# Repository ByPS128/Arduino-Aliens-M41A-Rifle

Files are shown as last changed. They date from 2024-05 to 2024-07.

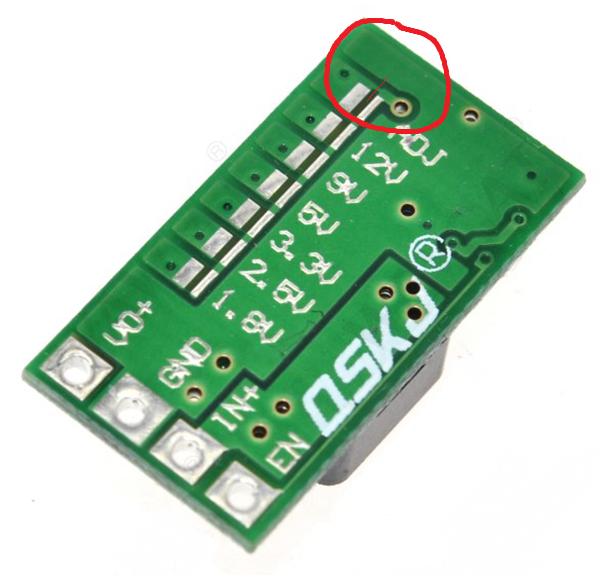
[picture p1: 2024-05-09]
doc/Micro Step-Down Converter-Adjustable/Micro Step-Down Converter-Adjustable.png

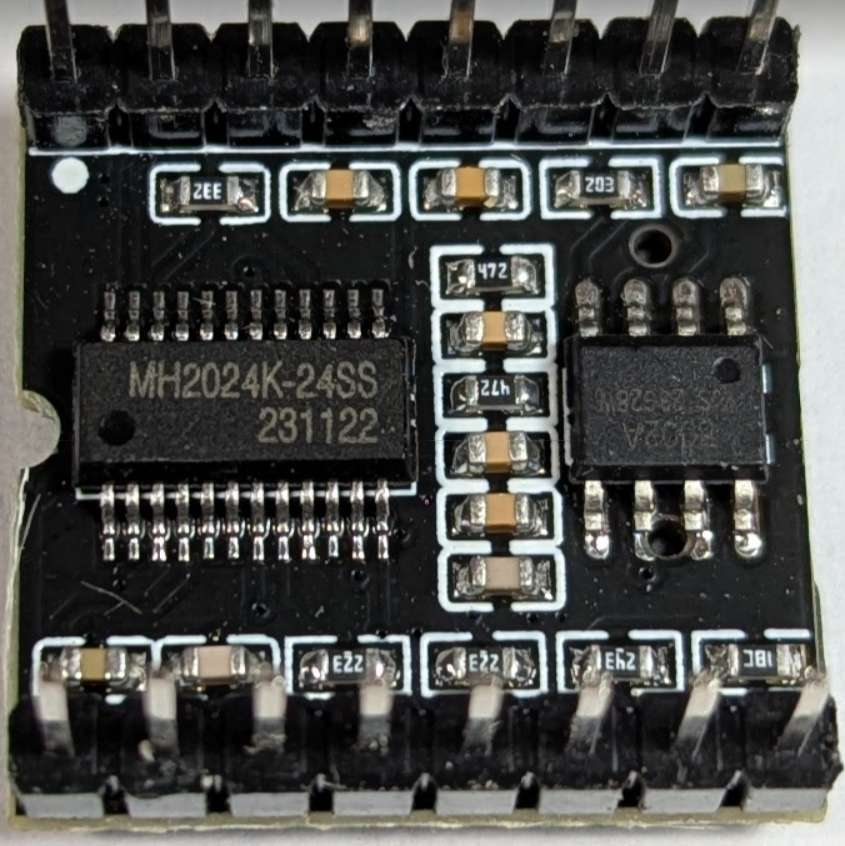
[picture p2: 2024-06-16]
doc/BAD-chip-photo/MH2024K-24SS.png

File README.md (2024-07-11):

# Welcome,

the project is a simple simulator of rifle and grenade launcher firing mockups of the popular M41A weapon from the legendary Aliens movie.
The hardware is implemented using an Arduino Nano and a DF Player (also known as the DF Robot) along with a few other peripherals.

#### In the document I will describe both HW and SW, browse it to the places you are interested in.

## So what does intended HW version consist of:

There are many M41A mock-ups on the market, including 3D printed ones. The version I was sounding did not have a working grenade launcher and it also did not have a retractable slide. We used the magazine space to house the electronics and so this version of the 3D printed rifle has quite a lot of limitations.
However, the software is easy to adapt for a larger application with multiple input signals.

* Arduino Nano
* DF Player for reproducing sounds
* Rotary Encoder with button to control volume, can be without button and it will work without the whole rotary encoder
* LED to illuminate the flashes in the barrel of the rifle
* LED to illuminate the barrel of the rifle
* Button to trigger the rifle's firing pin
* Button to trigger loading / firing of the grenade launcher
* Button to trigger the sound of the rifle bolt retracting
* Button to play magazine change sound
* Double digit 7 segment display
* Required resistors, capacitor and shocky protection diode

## 3D print
I made a 3D models of magazine foot where I placed:
* battery
* switch for turning on/off
* rotary encoder to adjust volume

You can use my 3D models for 3D printing if compatible with yours models of M41A rifle.

I will be glad if you use them, see here at Printables.com:

https://www.printables.com/cs/model/940214-m41a-rifle-magazine-foot-for-arduino-implementatio



I am using OnShape to create models, here is direct link if you are interested in:
https://cad.onshape.com/documents/143c32e288eb70a4674d24e8/v/e97b14a1ca8f76a05194cd48/e/891a4cec0397cb99cd8f56b7



## Want see how it works?
Here is updated video of the project in action with description of all functions:

https://www.youtube.com/watch?v=IwG0UBBIASA



## Schematic

I developed the scheme in KiCad (free). It's my first schematic, so please excuse me if I didn't choose some brands correctly. Alternatively, please modify the scheme and make a pull request. The schematic source files are in the KiCad directory.

https://www.kicad.org/

Schema preview:
M41A-Schematic

## Schama descriptions about condensators used as filter of peaks and noise:
To prevent the display from flickering after switching on the circuit, or even a flicker in the speaker, I recommend using an electrolytic and ceramic capacitor in parallel. Each type has different characteristics and they complement each other:

* 100 µF electrolytic capacitor: This capacitor is able to smooth out low frequency peaks and provide a stable power supply. Electrolytic capacitors have high capacitance and are suitable for low frequency filtering.

* 100 nF ceramic capacitor: This capacitor is capable of smoothing out high frequency peaks and noise. Ceramic capacitors have lower capacitance but are faster and more efficient for filtering high frequencies.

### So you should use both types of capacitors in parallel:
* Electrolytic capacitor **C1** (100 µF) between VCC and GND.
* Ceramic capacitor **C2** (100 nF) between VCC and GND.

### The order of the capacitors in the direction from source to consumer matters:
1. Ceramic capacitor (100 nF): this capacitor should be as close as possible to the power pins of the components (i.e. to the consumers). Ceramic capacitors are able to quickly filter out high frequency noise, which is useful for removing fast changes and interference.
2. electrolytic capacitor (100 µF). Electrolytic capacitors have higher capacitance and are able to smooth out low frequency peaks and stabilize the power supply.

## Estimation of current consumption
### Components:
* Arduino Nano: approximately 50 mA
* DFPlayer Mini: approximately 150-250 mA (without speaker)
* Speaker: up to 600 mA (at maximum power)
* Display with 74HC595: approximately 50-100 mA
* Other components (LEDs, switches, etc.): approx. 20-50 mA

### Total estimated current consumption
Approximately 870-1050 mA (considering all components at maximum power)

Calculation of capacitor capacitance required
It is common practice for filter capacitors to use 100-200 µF for every 100 mA of current draw.

Electrolytic capacitor **C3**
Required capacitance: (1050 mA / 100 mA) * 100-200 µF = 1050-2100 µF
Ceramic capacitor **C4**
Capacitance required: 100 nF to 1 µF (for high frequency noise)

### Recommended capacitances for capacitor.

#### C3 (electrolytic capacitor)
Recommended capacitance: 1000 µF to 2200 µF
This value will provide sufficient power supply filtering for all components.

#### C4 (ceramic capacitor)
Recommended capacitance: 100 nF to 1 µF
This value will help with high frequency noise filtering.

Schema file resides here: /KiCad/M41A/M41A.kicad_sch

and here is PDF version: /KiCad/M41A-Schematic.pdf

If you would like to open the schema, import the libraries I created. I couldn't find schematic marks for some components, so I created them with their footprints.
The library is in the directory: /KiCad/Project_Library.kicad_sym

### DF Player

I decided to use DF Player for playing sounds for several reasons:

* Low purchase price
* The possibility of controlling the serial line with its own simple protocol
* Clear organization of sound files on the SD card
* A large number of existing compatible libraries to support the protocol

However hend I made the experience that not every clone works properly. I was unlucky and the very first one I bought was built on the `MH2024K-24SS` chip. This has huge latency from the instruction to play the audio to the actual start of playback takes a second.
And that's unusable. That's why I bought a few more from different stores and came across a module with a `TD5580A` chip and it responds instantly. And that's why I recommend you use it. 

I used the protocol handler from an existing library and modified it to suit me better.

### Speaker

I used a 3W speaker. The specification of the DF Player says that the built-in amplifier will drive the 3W speaker to the maximum.
If you wanted to use a more powerful speaker, you would have to insert another amplifier between the player and the speaker and use a separate power supply.

**You can find the documentation for the DF player in the DOC directory, including communication protocol specs.**

### 2 digit 7 segment display

For displaying the remaining bullets in the rifle's magazine, I used, how else, red segment displays. And to get rid of a bunch of wires and resistors, I used a driver that is beautifully compact, works perfectly.
It contains a 74HC595 circuit for each segment. The displays used shared anode, so the segment lights up when its pin is at logic zero.



https://www.aliexpress.us/item/3256805033000283.html

### Rotary Encoder with button

I used this one, with built-in RC filter. Thanks to the filter, the dream was not to treat false presses.



https://www.aliexpress.us/item/3256805548024336.html

### LED diods

I used high brightness 5mm, warm white, 30mA LEDs
https://www.gme.cz/v/1492064/OptoSupply-OSM5DK5201A-LED-5mm-tepla-bila

## What this module can do, how it was designed

* Pressing and holding the trigger of the rifle starts playing the sound of firing and with each round fired the LED flashes to simulate a flash. At the same time, each shot will be read from the counter.
* When all rounds have been fired, the display shows 00 and the sound of the hammer striking empty is heard.
* Each subsequent pull of the trigger with an empty magazine will play this sound.
* The slide release button will also cause the magazine to load to 95 and cause the slide release sound to play.
* The magazine change button will set the magazine count to 95 rounds and trigger the magazine change and slide release sound.
* the grenade launcher trigger button will load a grenade with one press and play a sound consisting of several: chamber opening, grenade insertion and chamber closing.
* another press of the grenade launcher trigger will fire the grenade and play the sound of the grenade being fired. At the same time, the time to wait for the grenade to explode is randomly calculated. The next press of the grenade launcher trigger repeats charge, shot, charge, shot, etc.
* Rotating the rotary encoder changes the volume. When the gun is at rest and you change the volume, the display shows the volume numbers. The volume can also be changed while the sounds are playing. If a firing sound is playing and you are changing the volume, the display shows the cartridge level in the magazine as a priority.
* Pressing/pushing on the rotary encoder has 2 functions. A short press shows the current volume value on the display. A long press (a second or more) causes the status to be entered 

## Other features:

I made some sounds in multiple variations. This is so that the simulation does not appear monotonous. So every time I start shooting, a different option comes up. They repeat over time, but for the shot I made it so that each new playback plays a different file.
Similarly, the pulling of the weapon's bolt is solved, the sound of squeezing the trigger with an empty magazine is also solved.

## Sounds on SD card

The program is somehow built and expects concrete files on the sd card. DF Player uses mtak that I select a directory and a file in it. This is defined by numbers. So the directories are numbered and always with two digits, i.e. "01". I don't use them anymore. It would be easy to use the rotary encoder to select a different directory and thus select a different set of sounds, and suddenly the sounds could be from a specific existing weapon, or totally crazy sci-fi sounds, etc. In directory 01 there are files that must also be numbered in 3 places, i.e. 001, 002, etc. In the constants of the application, it is then defined which number has which sound.
For example (excerpt from AppConstants.h)

```
// I have some sounds in multiple variants and I randomly choose which variant to play.
// For this there are FIRST and LAST containers, which define the file numbers of the sounds of a given type.

// Sound file interval for rifle fire
static const int SAMPLE_RIFLE_FIRE_FIRST = 1;
static const int SAMPLE_RIFLE_FIRE_LAST = 6;

// Sound file interval for cock sound
static const int SAMPLE_COCK_FIRST = 10;
static const int SAMPLE_COCK_LAST = 14;

// Sound file interval for empty magazine, you rpes rifle fire and this empty file will play
static const int SAMPLE_EMPTY_MAGAZINE_FIRST = 20;
static const int SAMPLE_EMPTY_MAGAZINE_LAST = 24;
```

## File list on SD card.

Files must start with a number, but can continue with any name that describes the sound.
This is what my SD card looks like:

```
001-Shoot-95.wav
002-Shoot-95.wav
003-Shoot-95.wav
004-Shoot-95.wav
005-Shoot-95.wav
006-Shoot-95.wav
010-Cock-01-Sniper.wav
011-Cock-02.wav
012-Cock-03.wav
013-Cock-04.wav
014-Cock-05.wav
020-Empty.wav
021-Empty.wav
022-Empty.wav
023-Empty.wav
024-Empty.wav
030-MagazineEject-01.wav
031-MagazineEject-02.wav
040-MagazineLoad-01.wav
041-MagazineLoad-02.wav
042-MagazineLoad-03.wav
050-MagazineReload-01.wav
051-MagazineReload-02.wav
053-MagazineReloadCock-01.wav
054-MagazineReloadCock-02.wav
060-GranadeFire-01.wav
061-GranadeFire-02.wav
062-GranadeFire-03.wav
065-GranadeLoad-01.wav
066-GranadeExplosion-01.wav
067-GranadeExplosion-02.wav
070-Volume-01-Down.wav
071-Volume-02-Down.wav
072-Volume-03-Down.wav
073-Volume-04-Down.wav
074-Volume-05-Down.wav
080-Volume-01-Up.wav
081-Volume-02-Up.wav
082-Volume-03-Up.wav
083-Volume-04-Up.wav
084-Volume-05-Up.wav
090-CardInserted.wav
091-CardRemoved.wav
092-LowBattery.wav
093-VolumeSaved.wav
094-WeaponReady.wav
095-Click-01.wav
```

But in reality, the application, as its source codes define, uses the following files:
(Starting to play unused sounds is commented out in the application.)

```
001-Shoot-95.wav
002-Shoot-95.wav
003-Shoot-95.wav
004-Shoot-95.wav
005-Shoot-95.wav
006-Shoot-95.wav
010-Cock-01-Sniper.wav
011-Cock-02.wav
012-Cock-03.wav
013-Cock-04.wav
014-Cock-05.wav
020-Empty.wav
021-Empty.wav
022-Empty.wav
023-Empty.wav
024-Empty.wav
053-MagazineReloadCock-01.wav
054-MagazineReloadCock-02.wav
060-GranadeFire-01.wav
065-GranadeLoad-01.wav
066-GranadeExplosion-01.wav
093-VolumeSaved.wav
```

It is also essential to use the DriveSort app: [Anerty's Lair - DriveSort](https://www.anerty.net/software/file/DriveSort/) which sorts the files on the SD card so that they are physically organized in sequence.
This has a major impact on the delay/latency before the sound starts playing.

## How I made the sounds.

I searched in sound banks which provides free sounds for free download and use.
For example, I searched for gun cocking sounds under the keyword "cock" and one of the many useful ones I found is, for example, this one:
https://artlist.io/sfx/track/battle-rifles---fn-fal-cocking-gun/80693

It will probably take you some time to find the right sounds that you will like and fit for your application.

The firing of the M41A rifle is specific sound and is difficult to imitate. So I bought the game "Aliens Colonial Marines" and used the sounds from it.

To edit the sounds, I used the AudaCity software, which is free and can do everything necessary in it.
[https://www.audacityteam.org/](https://www.audacityteam.org/)

## Audio file format

DF Player can play many formats including MP3 in CD quality and stereo.
(It even has a simple equalizer, but I haven't used it, but you can, I have implemented functions to adjust the equalizer, just use them.)

The connection I used is monophonic, so using files containing stereo tracks is unnecessary workload for DF Player, and also such files are larger, which means that more power and time are needed to upload and process the file.
And this app (M41A) works well only when it responds instantly.
So, for these reasons, even after several attempts and tests, I decidedto use uncompresed WAV format, 8bit, mono with 22050 sample rate.
It sounds as good from that 3W speaker as the 16bit mono 44100. If you used a better speaker, then it is possible that you would use a better quality sound.

If you would use better quality sounds, there is no need to change anything in the application. The detection of the audio file format is fully under the control of DF Player.

When I wrote about organizing files on the SD card above, I mentioned the 01 directory that I use.
But you can easily have more such directories and the same numbered files in them. These can contain the same but higher quality sounds. By simply changing the value of one constant, you tell the application to use a different directory. And so you can easily test which sounds are better in your application.
The constant is named `DEFAULT_DIRECTORY_NUMBER` and resides in DFPlay.h file

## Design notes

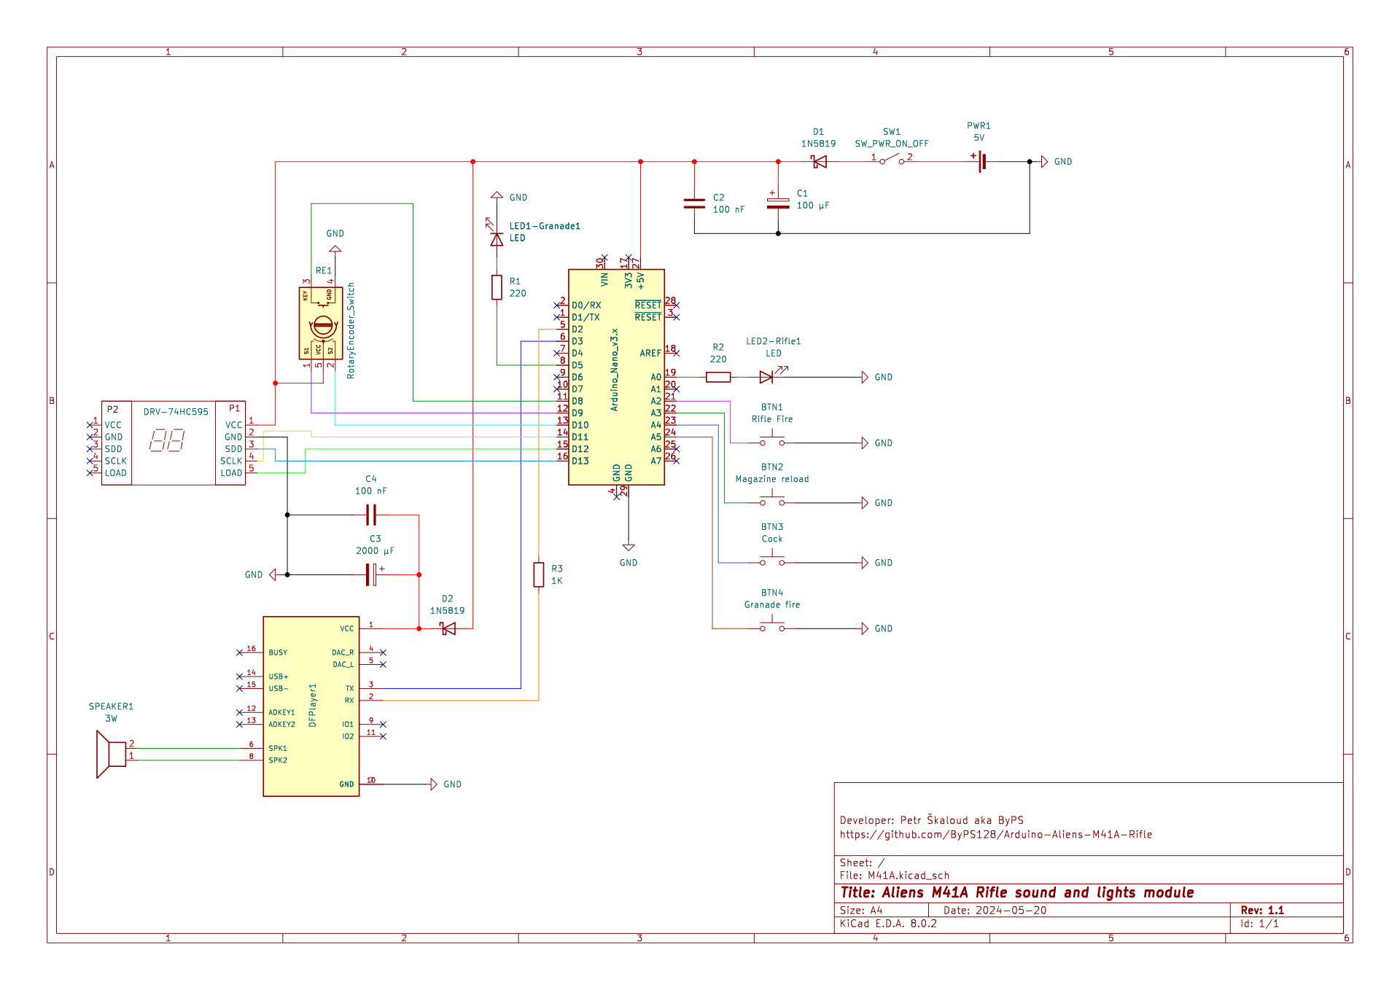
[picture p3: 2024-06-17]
KiCad/M41A-Schematic.png

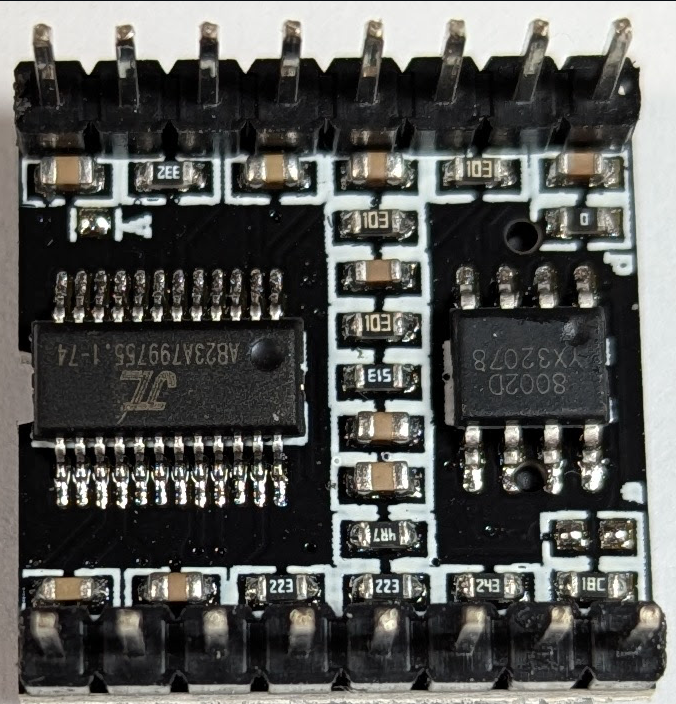
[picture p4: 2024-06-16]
doc/GOOD-chip-photo/A823A799755.png

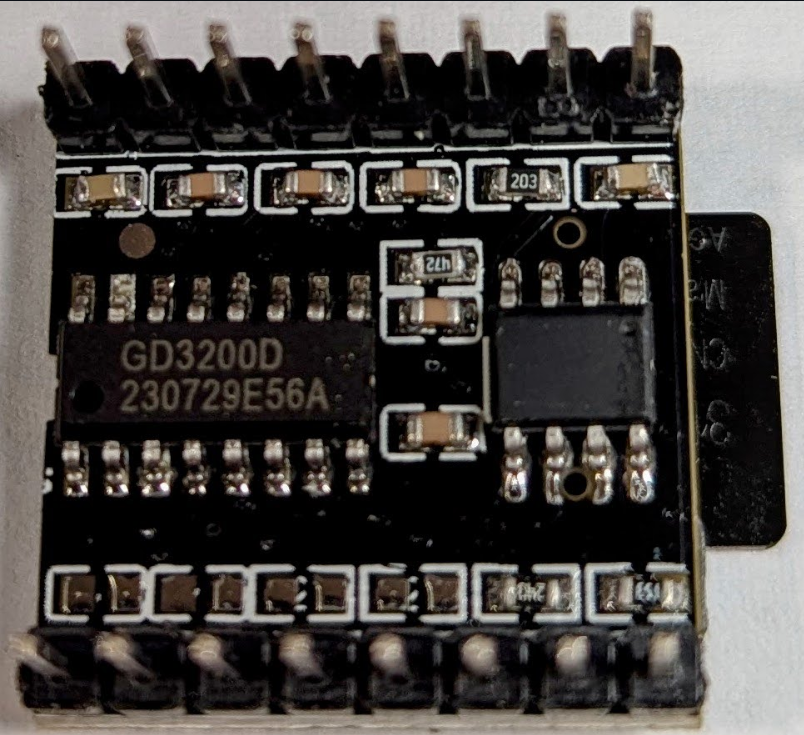
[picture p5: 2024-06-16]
doc/GOOD-chip-photo/GD3200D.png

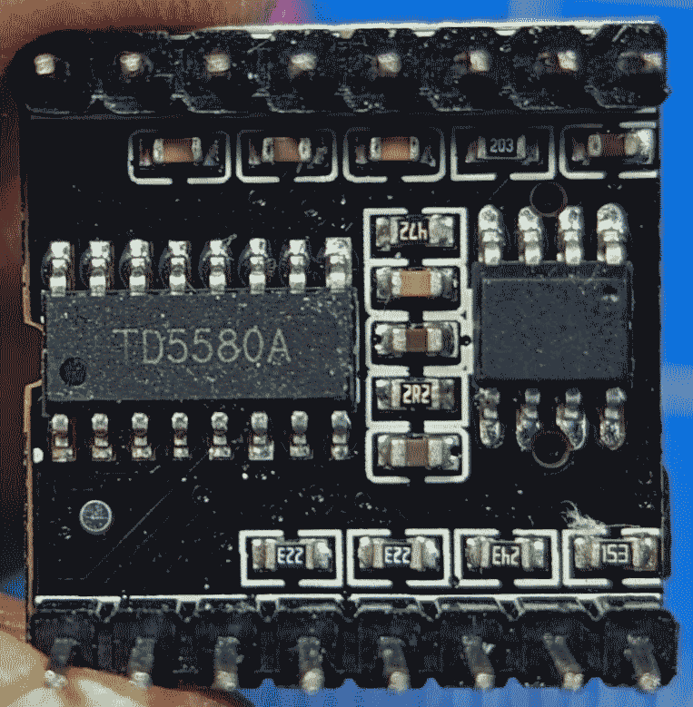
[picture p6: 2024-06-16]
doc/GOOD-chip-photo/TD5580A.png

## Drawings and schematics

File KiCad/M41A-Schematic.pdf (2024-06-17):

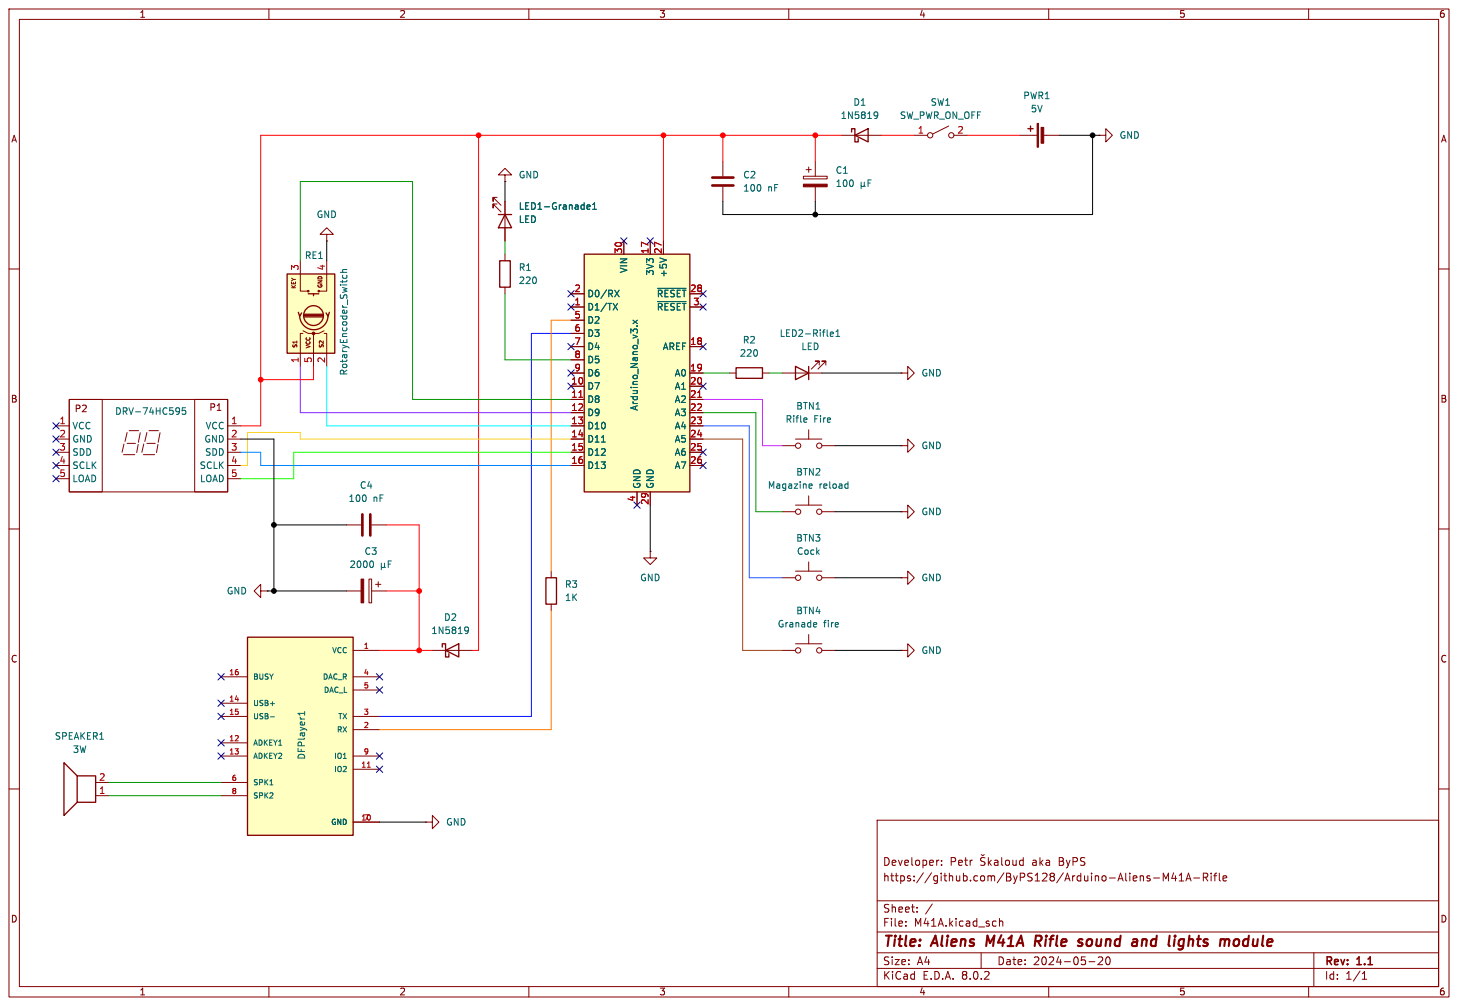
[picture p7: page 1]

File: M41A.kicad_sch Sheet: / https://github.com/ByPS128/Arduino-Aliens-M41A-Rifle

Id: 1/1 Title: Aliens M41A Rifle sound and lights module

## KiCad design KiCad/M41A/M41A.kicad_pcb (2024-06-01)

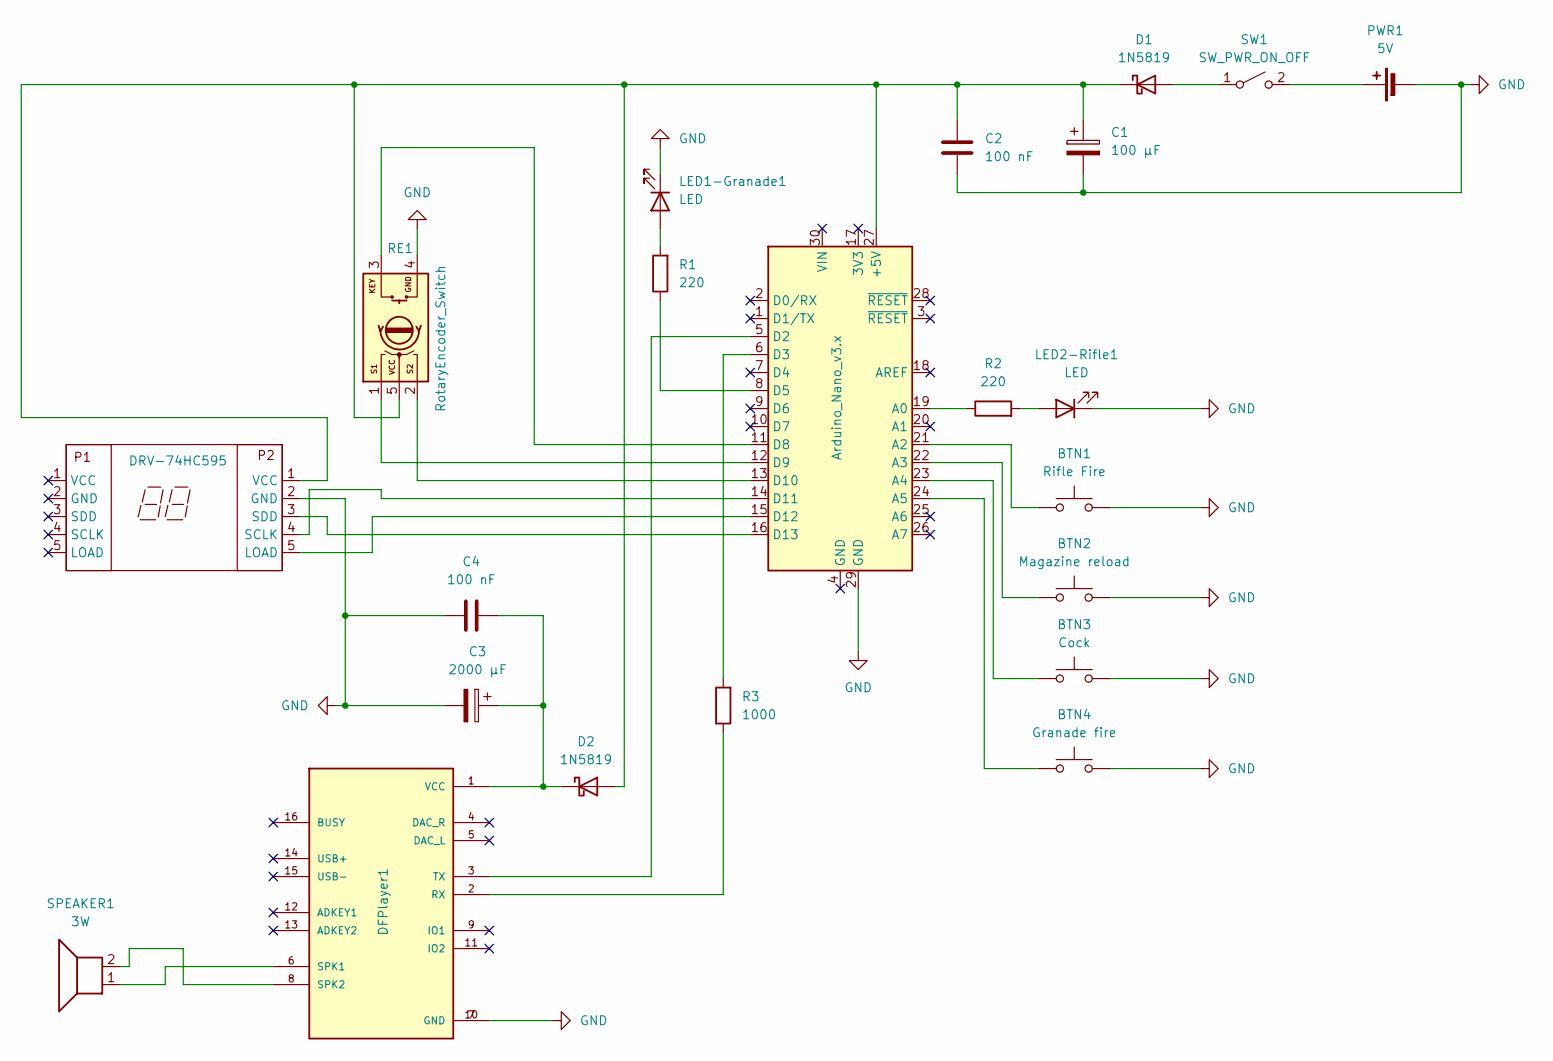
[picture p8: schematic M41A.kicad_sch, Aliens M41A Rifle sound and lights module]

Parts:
A1: Arduino_Nano_v3.x; Arduino_Nano
BTN1: Rifle Fire; Button Leads 2x 2.54
BTN2: Magazine reload; Button Leads 2x 2.54
BTN3: Cock; Button Leads 2x 2.54
BTN4: Granade fire; Button Leads 2x 2.54
C1: 100 µF; CP_Radial_D5.0mm_P2.50mm
C2, C4: 100 nF; C_Rect_L4.0mm_W2.5mm_P2.50mm
C3: 2000 µF; CP_Radial_D5.0mm_P2.50mm
D1, D2: 1N5819; D_DO-41_SOD81_P10.16mm_Horizontal
DFPlayer1: DFPlayer; MODULE_DFR0299
DRV-74HC595: Segment Display Leads 5x 2.54
LED1-Granade1, LED2-Rifle1: LED; LED Leads 2x 2.54
PWR1: 5V; Battery 4x 2.54
R1, R2: 220; R_Axial_DIN0204_L3.6mm_D1.6mm_P7.62mm_Horizontal
R3: 1000; R_Axial_DIN0204_L3.6mm_D1.6mm_P7.62mm_Horizontal
RE1: RotaryEncoder_Switch; RotaryEncoder Leads 5x 2.54
SPEAKER1: 3W; Speaker Leads 2x 2.54
SW1: SW_PWR_ON_OFF; SW_DIP_SPSTx01_Piano_10.8x4.1mm_W7.62mm_P2.54mm

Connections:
GND: A1.29 (GND), BTN1.2, BTN2.2, BTN3.2, BTN4.2, C1.2, C2.2, C3.2, C4.1, DFPlayer1.7 (GND), DFPlayer1.10 (GND), DRV-74HC595.2 (GND), LED1-Granade1.1 (K), LED2-Rifle1.1 (K), PWR1.2 (-), RE1.4 (GND)
unnamed: A1.27 (+5V), C1.1, C2.1, D1.1 (K), D2.2 (A), DRV-74HC595.1 (VCC), RE1.5 (VCC)
unnamed: A1.19 (A0), R2.1
unnamed: A1.21 (A2), BTN1.1
unnamed: A1.22 (A3), BTN2.1
unnamed: A1.23 (A4), BTN3.1
unnamed: A1.24 (A5), BTN4.1
unnamed: A1.5 (D2), DFPlayer1.3 (TX)
unnamed: A1.6 (D3), R3.2
unnamed: A1.8 (D5), R1.1
unnamed: A1.11 (D8), RE1.3 (KEY)
unnamed: A1.12 (D9), RE1.1 (S1)
unnamed: A1.13 (D10), RE1.2 (S2)
unnamed: A1.14 (D11), DRV-74HC595.4 (SCLK)
unnamed: A1.15 (D12), DRV-74HC595.5 (LOAD)
unnamed: A1.16 (D13), DRV-74HC595.3 (SDD)
unnamed: D1.2 (A), SW1.1 (A)
unnamed: C3.1, C4.2, D2.1 (K), DFPlayer1.1 (VCC)
unnamed: DFPlayer1.2 (RX), R3.1
unnamed: DFPlayer1.6 (SPK1), SPEAKER1.1
unnamed: DFPlayer1.8 (SPK2), SPEAKER1.2
unnamed: LED1-Granade1.2 (A), R1.2
unnamed: LED2-Rifle1.2 (A), R2.2
unnamed: PWR1.1 (+), SW1.2 (B)

Board: 2 copper layers, 22 parts (0 on the bottom side), 24 nets, no tracks yet.

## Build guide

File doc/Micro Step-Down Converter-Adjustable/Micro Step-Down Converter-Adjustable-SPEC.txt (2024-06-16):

Product link:
https://www.tinytronics.nl/en/power/voltage-converters/buck-(step-down)-converters/mini-dc-dc-adjustable-step-down-buck-converter-2a
https://www.laskakit.cz/mikro-step-down-menic--nastavitelny/

English:
Detailed Product Description
Micro Step-Down Converter, Adjustable
If you want to work with high current, ensure proper heat dissipation!

According to available information, there are modules on the market that are not equipped with the original chip and can cause damage to the electronics connected to such a module. The modules we supply are equipped with the original chip marked |AGC(N).

Specifications:
Control Circuit: MP2315
Input Voltage: DC 4.5-24V
Output Voltage: Adjustable and fixed output
Adjustable Range: 0.8-17V, fixed voltage 1.8V 2.5V 3.3V 5V 9V 12V
Output Current: 3A (max)
Efficiency: up to 97.5% (in 6.5V out 5V 0.7A)
Switching Frequency: 500KHz
Ripple Wave: 20mV (in 12V out 5V 3A)
Overvoltage Protection: no
Static Current: 0.85mA
Dimensions: 20x11x5mm

The default output voltage is adjustable, if you need a fixed output voltage, cut the path shown in the picture and then connect the contacts (1.8, 2.5, 3.3, 5, 9, 12V).

Czech:
Detailní popis produktu
Mikro step-down měnič, nastavitelný
Jestli chceš pracovat s velkým proudem, zajistěte si odvod tepla!

Podle dostupných informací se na trhu objevily tyto moduly, které nejsou osazeny originálním čipem a mohou způsobit zničení elektroniky připojené k takovému modulu. Námi dodávané moduly jsou osazeny originálním čipem s označením |AGC(N).

Specifikace:
Řídící obvod: MP2315
vstupní napětí: DC 4,5-24V
výstupní napětí: nastavitelný a pevný výstup
nastavitelný rozsah: 0,8-17V, pevné napětí 1.8V 2.5V 3.3V 5V 9V 12V
výstupní proud: 3A (max)
učinnost: do 97.5% (in 6.5 out 5V 0.7A)
frekvence spínání: 500KHz
ripple Wave: 20mV (in 12V out 5V 3A)
ochrana proti přepětí: ne
statický proud: 0.85mA
rozměry: 20x11x5mm

Výchozí výstupní napětí je nastavitelné, pokud potřebuješ pevně výstupní napětí, rozřízni cestu na obrázku a pak spoj kontakty (1.8, 2.5, 3.3, 5, 9, 12V)

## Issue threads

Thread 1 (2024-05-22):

I would like to be able to use your project for my rifle

longy55, 2024-05-22:
@ByPS128  Hello!
I am very interested in your project because I want to add light and sound to my m41a rifle.
I see that you have the arduino files, but I have not seen a wiring diagram for the electronics or the sound files. Is there a way to get them?
I would like to contribute in some way monetarily for all the work you have done if I can use it for myself.

Thanks in advance!

ByPS128, 2024-05-22:
Hey. Hey,
I'm glad you're interested in the project and that you're also a fan of the
cult movie Aliens ;)
Yes, I have the circuit diagram. I'm currently working on it and trying to
figure out how to wire it all up on the perfboard.

No need to contribute financially, I'm doing this as a bit of a hobby and
to learn new things. Anyway, thanks for the offer ;)

This is the segment display that the software supposes:
https://www.aliexpress.us/item/3256805033000283.html

And this is the used DF Player:
https://www.aliexpress.us/item/3256803321045196.html

Regards

st 22. 5. 2024 v 11:56 odesílatel longy55 ***@***.***> napsal:

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

longy55, 2024-05-22:
OK thank you very much for doing it altruistically!

Thanks for the information on the electronic components, what I have searched for on Github are the diagram and the sound files, but it is probably because I have not searched for them well hehe, I am going to look at everything carefully, I don't want to be annoying either.

ByPS128, 2024-05-22:
I couldn't find any sound files either. So I bought the game "Aliens
Colonial Marines" in which I muted the music and gunfire and recorded,
cleaned and edited the gun sounds in AudaCity (free). I converted them to
8bit mono 22K to get small but still good quality sound files. The size is
crucial for the delay before the sound starts playing.
The sounds that I missed or couldn't get clean I fished in various free
sound banks and then edited again as needed.
It is also essential to use the DriveSort app:
https://www.anerty.net/software/file/DriveSort/

which sorts the files on the SD card so that they are physically organized
in sequence. This also has a major effect on the delay before the sound
starts playing.

The SD card must contain the directory "01" in the root and these files in
it. it's the numbering that's important, the rest of the file name doesn't
matter:

001-Shoot-95.wav
002-Shoot-95.wav
003-Shoot-95.wav
004-Shoot-95.wav
005-Shoot-95.wav
006-Shoot-95.wav
010-Cock-01-Sniper.wav
011-Cock-02.wav
012-Cock-03.wav
013-Cock-04.wav
014-Cock-05.wav
020-Empty.wav
021-Empty.wav
022-Empty.wav
023-Empty.wav
024-Empty.wav
030-MagazineEject-01.wav
031-MagazineEject-02.wav
040-MagazineLoad-01.wav
041-MagazineLoad-02.wav
042-MagazineLoad-03.wav
050-MagazineReload-01.wav
051-MagazineReload-02.wav
053-MagazineReloadCock-01.wav
054-MagazineReloadCock-02.wav
060-GranadeFire-01.wav
061-GranadeFire-02.wav
062-GranadeFire-03.wav
065-GranadeLoad-01.wav
066-GranadeExplosion-01.wav
067-GranadeExplosion-02.wav
070-Volume-01-Down.wav
071-Volume-02-Down.wav
072-Volume-03-Down.wav
073-Volume-04-Down.wav
074-Volume-05-Down.wav
080-Volume-01-Up.wav
081-Volume-02-Up.wav
082-Volume-03-Up.wav
083-Volume-04-Up.wav
084-Volume-05-Up.wav
090-CardInserted.wav
091-CardRemoved.wav
092-LowBattery.wav
093-VolumeSaved.wav
094-WeaponReady.wav
095-Click-01.wav

I have used some sounds in several forms and the application plays them
randomly. So, for example, the sound of pressing a tap with an empty tray
doesn't sound the same and monotonous all the time. Similarly other sounds.
This makes the simulator more attractive. If you had fewer sound files,
their use is defined in AppConstantes.h, for example:
static const int SAMPLE_EMPTY_MAGAZINE_FIRST = 20;
static const int SAMPLE_EMPTY_MAGAZINE_LAST = 24;
a randomly selected file with a number from 20 to 24 is used to play the
empty sound

But some sound files are not used, like WeaponReady, VolumeUp/Down, Card
inserted/removed and LowBattery
Maybe in future with a little bit better sound player.

st 22. 5. 2024 v 12:41 odesílatel longy55 ***@***.***> napsal:

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

longy55, 2024-05-22:
It's incredible work you're doing man. I can't imagine the hours you would have had to spend to get the different sounds.
I'm embarrassed to ask you for those sound files without having made any effort, that's why I didn't mind contributing even if it was to the expense of the Colonial Marines :D

ByPS128, 2024-05-22:
I wouldn't want to violate anyone's copyright by publishing those sounds. So I'm going to have to disappoint you on this one. However, with a little determination, you can create the sounds. Look for keywords like "magazine load", "cock", etc.  Then you find sounds like this:
https://artlist.io/sfx/track/battle-rifles---fn-fal-cocking-gun/80693
Hope it help.

longy55, 2024-05-22:
I understand perfectly, thank you very much! I'll try to get the sounds out :)

ByPS128, 2024-05-22:
I updated the readme, check it out ;)
https://github.com/ByPS128/Arduino-Aliens-M41A-Riffle

longy55, 2024-05-23:
nice readme! great job, everything is understood perfectly :)

Closed 2024-06-16.

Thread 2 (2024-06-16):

Issue with getting sounds to play

PeteODDShop, 2024-06-16:
Hi @ByPS128
First of all, thank you so much for putting this amazing project together!

I'm currently putting together a prototype of the board, just wanting to use a single button for pulse rifle fire as a test. However, I am having issues getting the sound to play when I press the A2 trigger button (the ammo counter works as expected).

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

I have verified that the DF player works and the sounds are played if I trigger IO pins on the DF module.
I have followed your instructions on the directory for the sounds.

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

I am stumped on what else to try so I hope you can help!

Thanks again for this amazing project!

ByPS128, 2024-06-16:
Hi, I'm glad you were inspired by my project.
There are an incredibly large number of DF Player clones. I bought 8 of them from 8 different stores for testing purposes and each one is different in some way.
I would put it down to the chip version. It is possible that it will take more time to initialize, for example, or take larger pauses between commands.

Start by uncommenting the directive in the DFPlayer.h file on line 7:
`#define _DEBUG`.
Here direct link to that line: https://github.com/ByPS128/Arduino-Aliens-M41A-Riffle/blob/a8250e9c2921058aded1581b83136675a5db8e98/src/M41A/DFPlay.h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

Upload the program to the arduino and then connect to the arduino's serial line by activating `Serial Monitor`. This is done with the icon on the top right.
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

The arduino will reboot and the bottom of the Arduino IDE will start listing what the application is currently doing. Most of the information is from the DF Player. Without a doubt, the communication with the DF Player is the most sensitive part of the whole assembly.

`
Booting..

sending:7E FF 6 C 0 0 0 FE EF EF
CMD_RESET
Sent.

received: FF
sending:7E FF 6 3F 0 0 2 FE BA EF
CMD_INIT: 2
Sent.

received: 7E FF 6 3F 0 0 2 FE BA EF
CMD_INIT: 2

sending:7E FF 6 6 0 0 A FE EB EF
CMD_SET_VOLUME 10
Sent.

DFPlayer ready
M41A player ready
received: 7E FF 6 3F 0 0 2 FE BA EF
CMD_INIT: 2

sending:7E FF 6 6 0 0 A FE EB EF
CMD_SET_VOLUME 10
Sent.

sending:7E FF 6 F 0 1 C FE DF EF
CMD_SET_PLAY_FOLDER_FILE folder: 1, file: 12
Sent.

received: 7E FF 6 3D 0 0 9 FE B5 EF
Playback finished, file: 9
received: 7E FF 6 3D 0 0 9 FE B5 EF
Playback finished, file: 9
`

This is what communication looks like with DF Player, which works well.
Try to compare the outputs. Or if they differ, put your output here.

The following constants are in the DFPlay.h file:
`
  static const int DFPLAYER_RESET_TIME = 1000;
  static const int DFPLAYER_INIT_TIME = 500;
`

You can try experimenting with their values. The values are in milliseconds.

There are more options to play around with, but let's start with the dump ;)

A little tip, if you have the serial monitor on and want to re-upload a new version. you need to deactivate the serial monitor first. I often forget this and the upload fails afterwards.

ByPS128, 2024-06-16:
These are the chips I had the opportunity to test. What's yours?

This is amazing and absolutely the best.
Chip: TD5580A
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

Also great.
Chip: GD3200D
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

Also great.
Chip: A823A799755
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

I have received several versions with this chip and it is the worst option you can buy:
MH2024K-24SS - realy BAD.
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

PeteODDShop, 2024-06-16:
Hi @ByPS128
Thanks for responding so quickly!

I took onboard what you mentioned about bad DFPlayer Mini clones so I got DFR0299 especially for this one.
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

Definitely something wrong with the fire button is pressed as per monitor output below;
`

Booting..

sending:7E FF 6 C 0 0 0 FE EF EF
CMD_RESET
Sent.

sending:7E FF 6 3F 0 0 2 FE BA EF
CMD_INIT: 2
Sent.

sending:7E FF 6 6 0 0 16 FE DF EF
CMD_SET_VOLUME 22
Sent.

DFPlayer ready
M41A player ready

sending:7E FF 6 6 0 0 16 FE DF EF
CMD_SET_VOLUME 22
Sent.

sending:7E FF 6 F 0 1 C FE DF EF
CMD_SET_PLAY_FOLDER_FILE folder: 1, file: 12
Sent.

sending:7E FF 6 F 0 1 2 FE E9 EF
CMD_SET_PLAY_FOLDER_FILE folder: 1, file: 2
Sent.

sending:7E FF 6 16 0 0 1 FE E4 EF
Unknown command: 16, params: 1
Sent.

PeteODDShop, 2024-06-16:
Just tested a DFplayer Mini with Chip: TD5580A and I'm getting the same result.

ByPS128, 2024-06-16:
> Ah, this is embarrassing.
>
> The Tx and Rx were incorrect on my board D:

No problem, I'll be happy to help if possible.
I see you have the original ;) I couldn't find it here.

So the problem was caused by the Rx and Tx wiring. can you confirm?
You see, I wouldn't even have thought that they designed the board differently.
So does this mean that your sound module is already working and button presses are playing sounds?

PeteODDShop, 2024-06-16:
I can confirm it was the D2 and D3 pins on the arduino nano

src/M41A/AppConstants.h
static constexpr uint8_t PIN_MP3_TX = 2; // Connects to module's RX
static constexpr uint8_t PIN_MP3_RX = 3; // Connects to module's TX

But unless I'm reading the Kicad schematic incorrectly, it shows that the DFplayer's RX pin connected to D3 and this is what I followed.

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

I hope my mistake can help others not make the same one!

Thanks @ByPS128 for the support! I will keep building and let you know how it goes :D

ByPS128, 2024-06-16:
Oh, my God, you're right, I drew it wrong on the schematic. I'm looking at the breadboard of the prototype wiring and it's really like that. I'm ashamed, such a schoolboy mistake. I'm sure you spent hours looking for it. Thanks for finding the mistake. I need to get new close-up glasses :D
I'm sorry. I'll fix the schematic tomorrow and post it here.
Be sure to let me know how you get on with the implementation. Fingers crossed.

ByPS128, 2024-06-17:
Corrected i KiCAD files, pdf, svg and readme.md files also.
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

PeteODDShop, 2024-06-17:
Thanks again for your help @ByPS128
Will keep you updated on the build :)

ByPS128, 2024-06-17:
Closing as solved.

PeteODDShop, 2024-06-25:
Hi @ByPS128
Just a quick update on the build. The 3d print I have was never designed for internals so it's a bit of a squeeze.

https://youtu.be/PtkeMC004Nk

PeteODDShop, 2024-06-26:
Looking good! Love the modification to the magazine cap.

ByPS128, 2024-07-11:
> Looking good! Love the modification to the magazine cap.

Hi, I released video with all functions in current configuration. HOpe you will watch ;)
How it is going with yours build?

https://www.youtube.com/watch?v=IwG0UBBIASA

PeteODDShop, 2024-07-11:
Great job on the new vid!
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

Few more bits to do on mine. Ammo counter cover, weathering, mag release but almost there :D

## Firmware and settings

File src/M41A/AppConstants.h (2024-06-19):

#pragma once

#include <Arduino.h>

// Use pins 2 and 3 to communicate with DFPlayer Mini
static constexpr uint8_t PIN_MP3_TX = 2; // Connects to module's RX
static constexpr uint8_t PIN_MP3_RX = 3; // Connects to module's TX

static constexpr int MAX_VOLUME = 30; // DFPlayer has a volume range from 0 to 30, it freezes at 24 in my case when arduino is powered by USB, the 3W speker and build in amplifier eats too much.
static constexpr int VOLUME_ADDRESS = 10; // EEPROM address for volume storage
static constexpr int INIT_FLAG_ADDRESS = 9;  // Address for depositing the control flag
static constexpr byte INITIALIZED_FLAG = 0xA5;  // Some specific value for checking initialization, typically greater than MAX_VOLUME, to indicate that the volume has not yet been stored.
static constexpr byte DEFAULT_VOLUME_VALUE = 20;

static constexpr int MAX_BULLETS_COUNT = 95; // Count of bullets in full magazine

// Pin assignments
constexpr int RIFLE_TRIGGER_PIN = A2;        // Rifle trigger button
constexpr int MAGAZINE_RELOAD_PIN = A3;      // Magazine reload button
constexpr int RIFLE_COCK_PIN = A4;           // Rifle cocking button
constexpr int GRENADE_TRIGGER_PIN = A5;      // Grenade launcher trigger button
constexpr int RESERVED_BUTTON_PIN = A6;      // Reserved button

constexpr int ROTARY_S1_PIN = 9;             // Volume rotary encoder (S1)
constexpr int ROTARY_S2_PIN = 10;            // Volume rotary encoder (S2)
constexpr int ROTARY_BUTTON_PIN = 8;         // Volume rotary encoder button (KEY)

constexpr int LED_RIFLE_PIN = A0;            // LED for rifle barrel
constexpr int LED_GRENADE_PIN = 5;           // LED for grenade barrel (must be PWM for animation)

// Connections to 74HC595 shift register
constexpr int LATCH_PIN = 12;                // 74HC595 RCLK  - ST_CP (LOAD)
constexpr int CLOCK_PIN = 11;                // 74HC595 SRCLK - SH_CP (SCLK)
constexpr int DATA_PIN = 13;                 // 74HC595 SER   - DS    (SDD)

// Time constants
constexpr int VOLUME_DISPLAY_TIMEOUT = 3000; // Time in milliseconds for how long the volume will be displayed on the screen
// after how long it takes to substract one bullet from the magazine.
// My sound files for rifle shoot takes 8.5-9 seconds, so tis is the calculation of substraction interval:
// 90ms * 95 bullets = 8550ms = 8.55s
constexpr int FIRE_COUNTDOWN_INTERVAL = 90;  // Interval in milliseconds between each bullet subtraction during firing
constexpr int RIFLE_FIRE_FLASH_TIMEOUT = 60; // Duration in milliseconds for the rifle LED flash during firing
constexpr int GRENADE_FLASH_FADEOUT_TIME = 700; // Duration in milliseconds for the grenade LED fadeout animation
constexpr int TRANSITION_DURATION_PER_10_UNITS = 60; // Duration in milliseconds for each 10 units of transition in displayAnimator

// Other constants
constexpr unsigned long LONG_PRESS_TIME = 1000; // Duration in milliseconds to detect a long button press

// I have some sounds in multiple variants and I randomly choose which variant to play.
// For this there are FIRST and LAST containers, which define the file numbers of the sounds of a given type.

// Sound file interval for rifle fire
static constexpr int SAMPLE_RIFLE_FIRE_FIRST = 1;
static constexpr int SAMPLE_RIFLE_FIRE_LAST = 6;

// Sound file interval for cock sound
static constexpr int SAMPLE_COCK_FIRST = 10;
static constexpr int SAMPLE_COCK_LAST = 14;

// Sound file interval for empty magazine, you press rifle fire and this empty file will play
static constexpr int SAMPLE_EMPTY_MAGAZINE_FIRST = 20;
static constexpr int SAMPLE_EMPTY_MAGAZINE_LAST = 24;

// Sound file interval for ejecting of the magazine
static constexpr int SAMPLE_MAGAZINE_EJECT_FIRST = 30;
static constexpr int SAMPLE_MAGAZINE_EJECT_LAST = 31;

// Sound file interval for loading of the magazine
static constexpr int SAMPLE_MAGAZINE_LOAD_FIRST = 40;
static constexpr int SAMPLE_MAGAZINE_LOAD_LAST = 42;

// Sound file interval for ejecting + loading magazine + cock
// it depends how you make your own sound files and which hardware you use.
static constexpr int SAMPLE_MAGAZINE_RELOAD_FIRST = 53;
static constexpr int SAMPLE_MAGAZINE_RELOAD_LAST = 54;

// This Grenade load sound file includes actions:
// open chamber + put grenade to chamber + close chamber. 3 actions in one sound file.
// Again it depends on hardware. My 3D printed M41A has no functional grenade mechanics.
static constexpr int SAMPLE_GRENADE_LOAD = 65;
static constexpr int SAMPLE_GRENADE_FIRE = 60; // 60-62 - variations
static constexpr int SAMPLE_GRENADE_EXPLOSION = 66; // 66-67 - variations

// NOT USED comment means: DF Player is very simple audio device and playing different sounds in short frequency of change is too much for it.
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

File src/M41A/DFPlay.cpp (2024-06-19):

#include "DFPlay.h"

// Constructor initializes the SoftwareSerial with the specified pins
DFPlay::DFPlay()
  : dfPlayerSerial(PIN_MP3_RX, PIN_MP3_TX) {
}

// Setup initializes the DFPlayer with the specified volume and acknowledgment setting
void DFPlay::setup(byte newVolume, bool enableAck) {
  playing = false;

  dfPlayerSerial.begin(9600);
  if (enableAck) {
    enableACK();
  } else {
    disableACK();
  }

  //reset(true); // At boot time the reset is not necessary.
  init(false); // false parameter means: no not wait

  setVolume(newVolume);
  waitAndEatAvailable(DFPLAYER_INIT_TIME);

#ifdef _DEBUG
  Serial.println("DFPlayer ready");
#endif
}

// Update the status of the DFPlayer
void DFPlay::update() {
  available();
}

// Reset the DFPlayer module
void DFPlay::reset(bool performWaiting) {
  exe_cmd(CMD_RESET, 0, 0);
  if (performWaiting) {
    waitAndEatAvailable(DFPLAYER_RESET_TIME); // Wait for the DFPlayer to restart
  }
}

// Initialize the DFPlayer module
void DFPlay::init(bool performWaiting) {
  exe_cmd(CMD_INIT, 0, DFPLAYER_DEVICE_SD);
  if (performWaiting) {
    waitAndEatAvailable(DFPLAYER_INIT_TIME); // Wait for the DFPlayer to initialize
  }
}

// Play a specific file in a specific folder
void DFPlay::play(byte directoryNumber, byte fileNumber) {
  exe_cmd(CMD_SET_PLAY_FOLDER_FILE, directoryNumber, fileNumber);
  playing = true;
}

// Play a specific file in the default folder
void DFPlay::play(byte fileNumber) {
  play(DEFAULT_DIRECTORY_NUMBER, fileNumber);
}

// Stop the playback
void DFPlay::stop() {
  exe_cmd(CMD_STOP, 0, 1);
  playing = false;
}

// Pause the playback
void DFPlay::pause() {
#ifdef _DEBUG
  Serial.print(F("Is playing: "));
  Serial.print(playing);
#endif
  if (playing) {
    exe_cmd(CMD_PAUSE_PLAY, 0, 0);
    playing = false;
  }
}

// Check if the player is currently playing
bool DFPlay::getPlaying() {
  return playing;
}

// Get the current volume
byte DFPlay::getVolume() {
  return (byte)(volume & 0xFF);
}

// Set a new volume
void DFPlay::setVolume(byte newVolume) {
  volume = newVolume;
  exe_cmd(CMD_SET_VOLUME, 0, volume);
}

// Increase the volume by one step
void DFPlay::volumeIncrement() {
  volume++;
  if (volume > MAX_VOLUME) {
    volume = MAX_VOLUME;
  }
  exe_cmd(CMD_SET_VOLUME, 0, volume);
}

// Decrease the volume by one step
void DFPlay::volumeDecrement() {
  volume--;
  if (volume < 0) {
    volume = 0;
  }
  exe_cmd(CMD_SET_VOLUME, 0, volume);
}

// Cycle through equalizer settings
void DFPlay::cycleEqualizer() {
  eqset = eqset + 1;
  if (eqset == EqBase + 1) {
    eqset = EqNormal;
  }

  setEqualizer(eqset);
}

// Set the equalizer to a specific type
void DFPlay::setEqualizer(byte equalizerType) {
  exe_cmd(CMD_SET_EQ, 0, equalizerType);
}

// Play an advertisement track
void DFPlay::playAdvertise(int track) {
  exe_cmd(CMD_PLAY_ADVERT, 0, track);
}

// Stop the advertisement
void DFPlay::stopAdvertise() {
  exe_cmd(CMD_STOP_ADVERT, 0, 0);
}

// Execute a command with parameters
void DFPlay::exe_cmd(byte CMD, byte Par1, byte Par2) {
  available();
  uint32_t submitGap = millis() - lastSubmitMillis;

  // Ensure a minimum gap of 30ms between commands
  if (submitGap < 30) {
    delay(30 - submitGap);
  }

  lastSubmitMillis = millis();

  _sending[Stack_Command] = CMD;
  _sending[Stack_Parameter] = Par1;
  _sending[Stack_Parameter + 1] = Par2;

  uint16_t checksum = calculateCheckSum(_sending);

  _sending[Stack_CheckSum] = (byte)(checksum >> 8);        // High byte of checksum
  _sending[Stack_CheckSum + 1] = (byte)(checksum & 0xFF);  // Low byte of checksum

  sendStack();
}

// Handle received messages
bool DFPlay::handleMessage(uint8_t type, uint16_t parameter) {
  _receivedIndex = 0;
  _handleType = type;
  _handleParameter = parameter;
  _isAvailable = true;

  return _isAvailable;
}

// Handle errors and reset sending flag
bool DFPlay::handleError(uint8_t type, uint16_t parameter) {
  handleMessage(type, parameter);
  _isSending = false;

#ifdef _DEBUG
  Serial.println("Error");
#endif

  return false;
}

// Wait for available data within a specified duration
bool DFPlay::waitAvailable(unsigned long duration) {
  unsigned long timer = millis();
  if (!duration) {
    duration = _timeOutDuration;
  }
  while (!available()) {
    if (millis() - timer > duration) {
      return handleError(TimeOut);
    }

    delay(0);
  }

  return true;
}

// Wait for available data within a specified duration
void DFPlay::waitAndEatAvailable(unsigned long duration) {
  unsigned long timeOut = millis() + duration;
  while (timeOut > millis() || dfPlayerSerial.available()) {
    if (dfPlayerSerial.available()) {
      dfPlayerSerial.read();
      continue;
    }
    delay(2);
  }
}

// Convert a byte array to uint16_t
uint16_t DFPlay::arrayToUint16(uint8_t *array) {
  uint16_t value = *array;
  value <<= 8;
  value += *(array + 1);
  return value;
}

// Validate the received stack
bool DFPlay::validateStack() {
  return calculateCheckSum(_received) == arrayToUint16(_received + Stack_CheckSum);
}

// Parse the received stack
void DFPlay::parseStack() {
  uint8_t handleCommand = *(_received + Stack_Command);
  if (handleCommand == CMD_ACK) {
#ifdef _DEBUG
    Serial.println("ACK feedback");
#endif
    _isSending = false;
    return;
  }

  _handleCommand = handleCommand;
  _handleParameter = arrayToUint16(_received + Stack_Parameter);
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

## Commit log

2024-05-09 Volume button behavior change. it rcognize short and long press now.
    [AppConstants.h, M41aSimulator.cpp]
2024-05-20 Added CiCad schematic and PCB
    [M41A.kicad_pcb, M41A.kicad_sch]
2024-05-20 Actrualized KiCad project library.
    [M41A.kicad_pcb, M41A.kicad_sch]
2024-05-20 Little chage in connection to key pin of rotary encoder.
    [M41A.kicad_pcb, M41A.kicad_sch]
2024-05-22 +KiCad schematic files
    [M41A.kicad_pcb, M41A.kicad_sch]
2024-05-28 Actualized schema
    [M41A.kicad_pcb, M41A.kicad_sch]
2024-06-01 Updated scheme
    [M41A.dsn, M41A.kicad_pcb, M41A.kicad_sch]
2024-06-14 Long press button fix. Minor improvements to the StopPlayback command..
    [AppConstants.h]
2024-06-16 Addes images of good chips of DF player and alno of bad chips. Added product spec of Adjustable Step-down Buck Converter 2A
2024-06-17 Corrected schema wiring between arduino and df player.
    [M41A.kicad_sch]
2024-06-17 Update README.md - schematic correction
2024-06-17 Colored schematic wiring for better orientation.
    [M41A.kicad_sch]
2024-06-19 Better app start, speaker first weapon cock after turning on sometimes played at full volume because it didn't accept the volume setting.
    [AppConstants.h, DFPlay.cpp, DFPlay.h]
